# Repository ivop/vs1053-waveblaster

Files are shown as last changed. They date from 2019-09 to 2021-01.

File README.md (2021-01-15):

#VLSi SynthRoarer -- A vs1053/vs8053-waveblaster module
-------------------------------------------------
By using a vs1053/vs8053, we present to you an ideal, low-cost, easy to solder, some what compact and open source WaveBlaster module.
_________________________________________________
Introducing VLSi SynthRoarer.
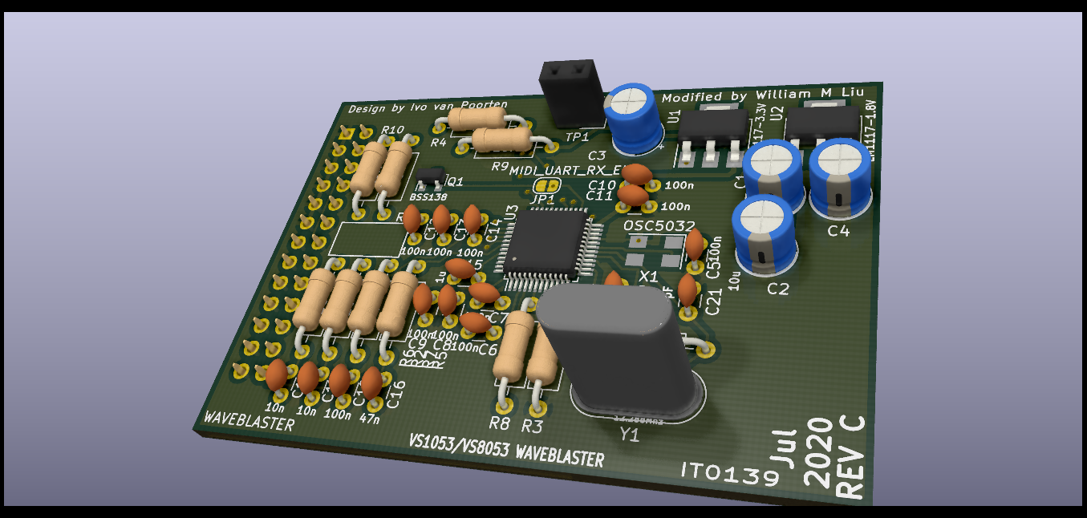
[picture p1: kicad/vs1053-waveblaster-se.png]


*Support General Midi with 128 GM1 instruments 61 GM2 Bank 0 precussion sounds up to 64 notes polyphony and stereo output @48Khz 16bit

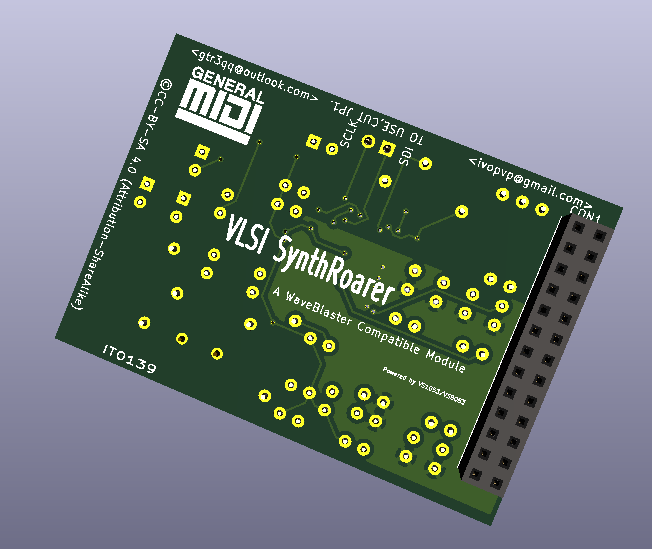
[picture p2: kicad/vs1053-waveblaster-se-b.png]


How's it sound?
--------------
Here is a sample from chip manufacture.

http://www.vlsi.fi/fileadmin/software/VS10XX/vs1053mid.mp3

Notes
------------------------
It's been tested on a old ESS 688 audiodrive sound card.

REV B and REV A is in gergber/old stable.7z

REV C IS BASICALLY REV B,their schematic is the same.

REV A = vs1053-waveblaster

REV C = vs1053-waveblaster-se

Pictures
----------------------------
Here's a view of it been fully assembled and not been. (It says REV C, but it's actually REV B).

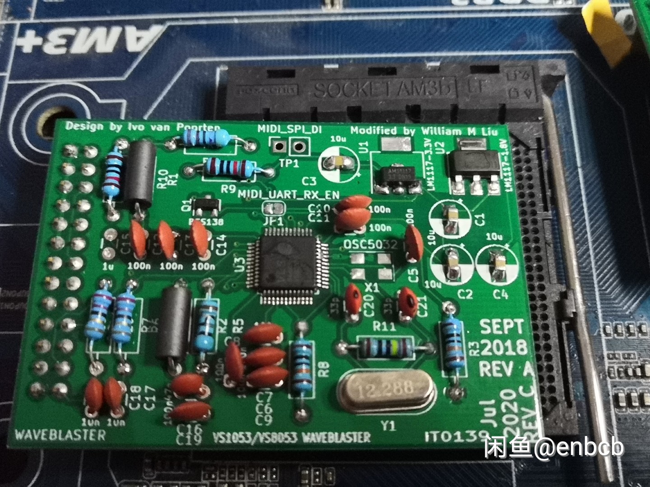
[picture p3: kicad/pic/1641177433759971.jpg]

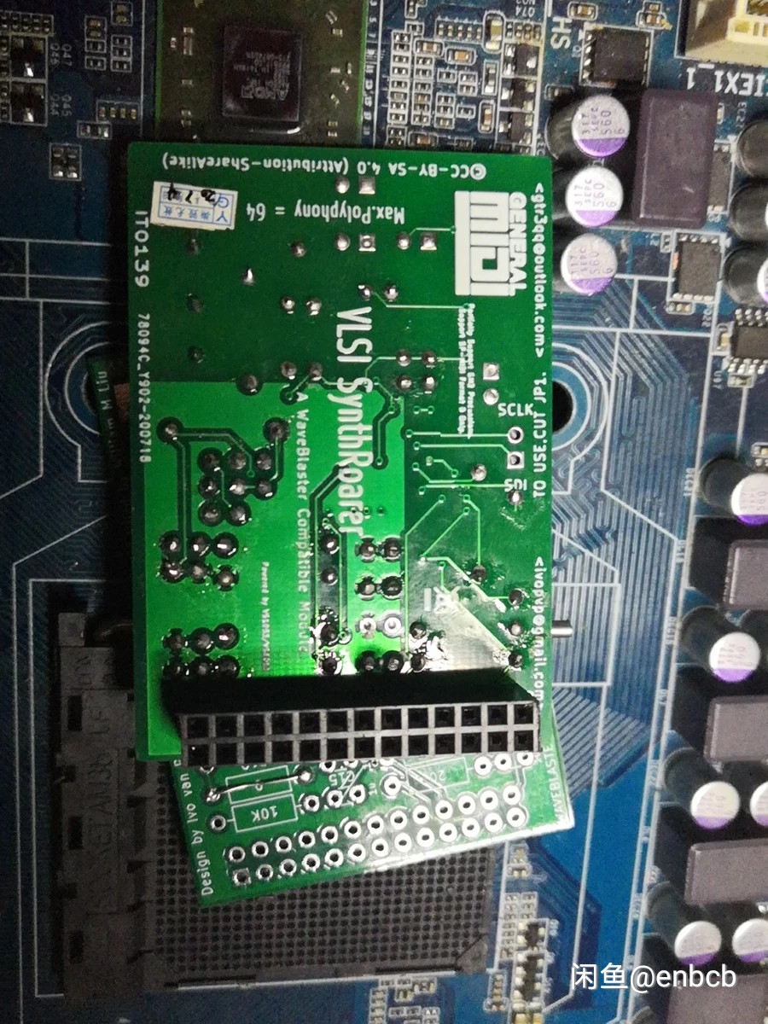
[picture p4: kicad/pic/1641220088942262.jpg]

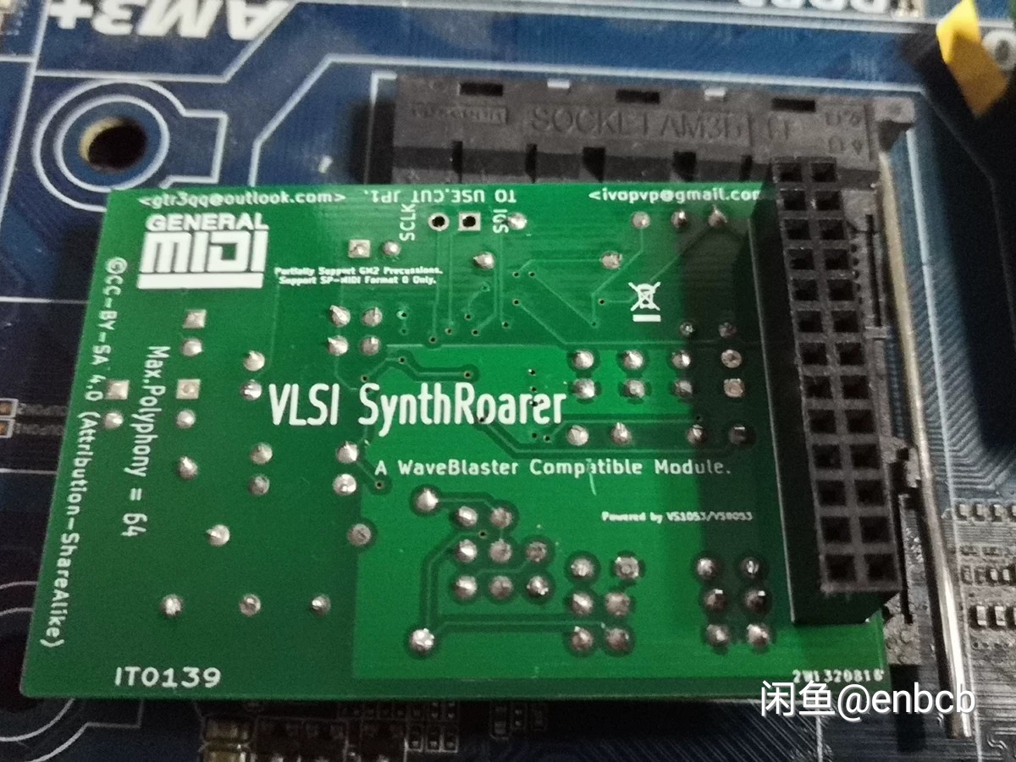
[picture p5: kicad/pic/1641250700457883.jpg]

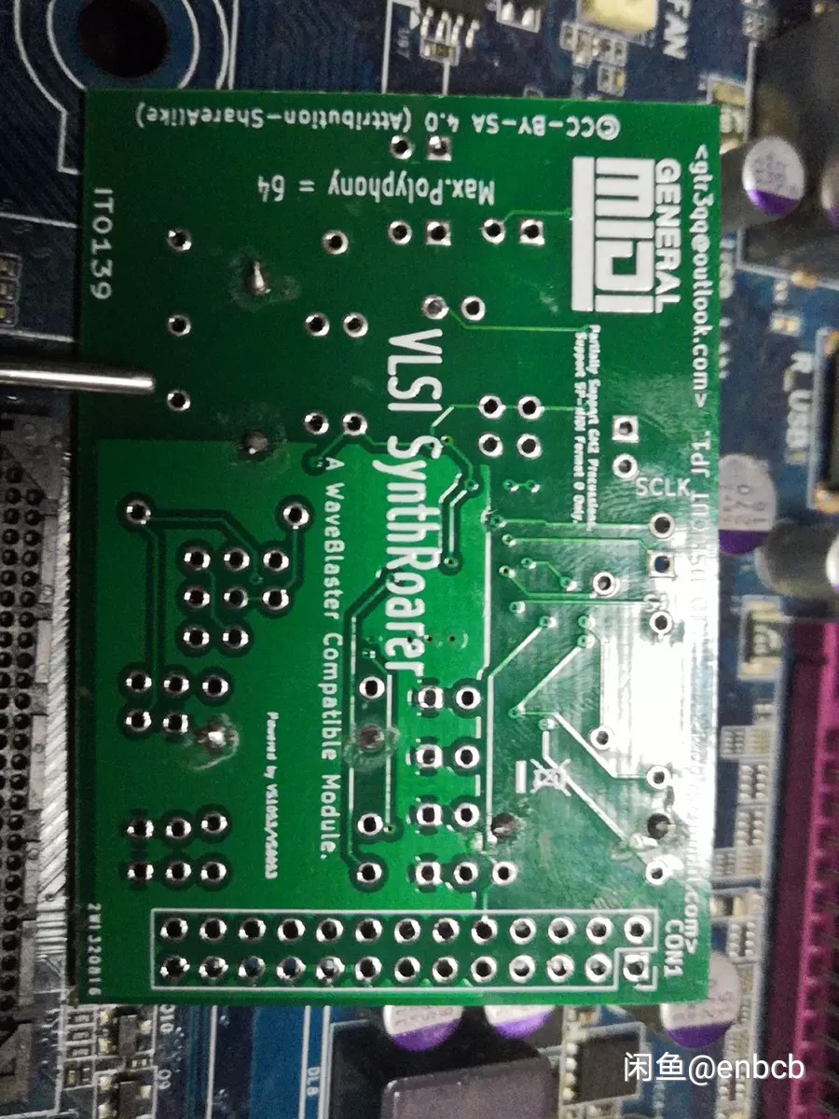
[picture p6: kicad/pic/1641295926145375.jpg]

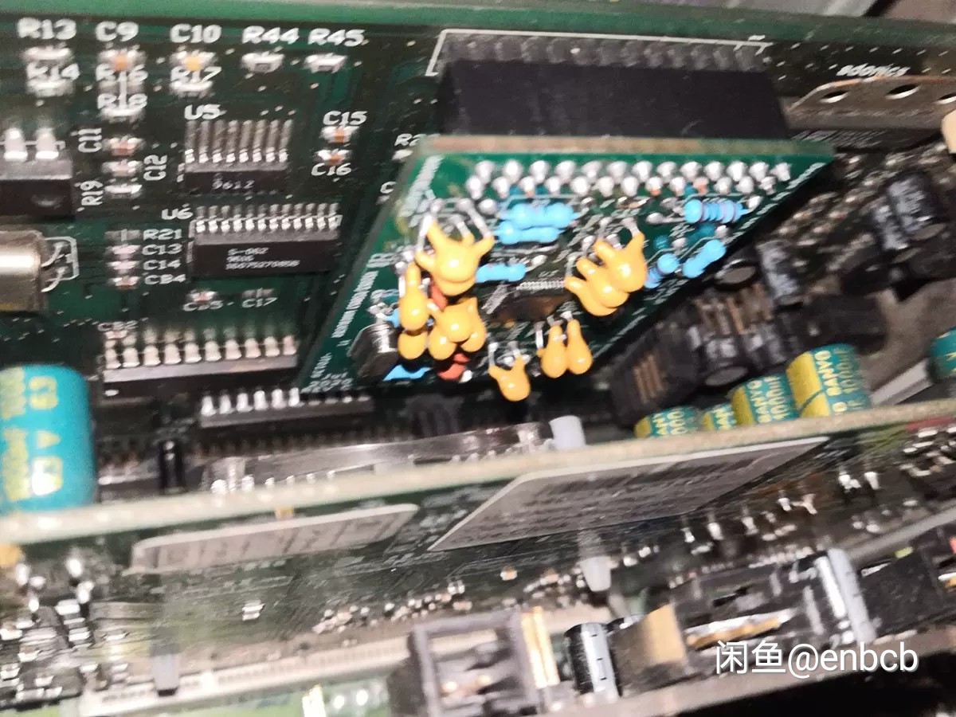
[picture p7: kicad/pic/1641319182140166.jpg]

*Look,it is working on my soundcard.

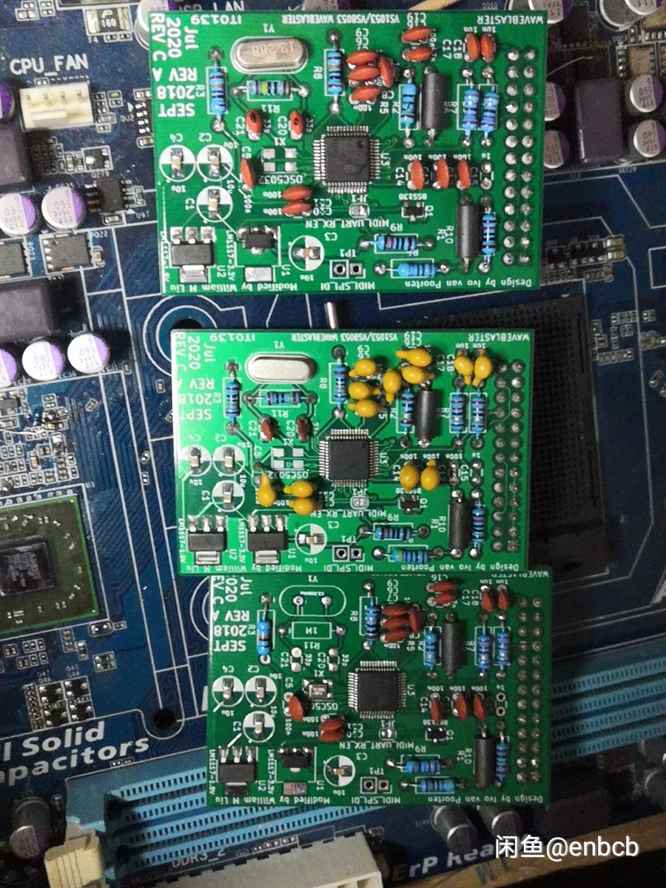
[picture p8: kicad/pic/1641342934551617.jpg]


*a. It is your choice to use crystal or oscillator.

*b. Both vs8053 and vs1053 can be used. There're no diffience in the MIDI implementation. Just buy the cheapest one.

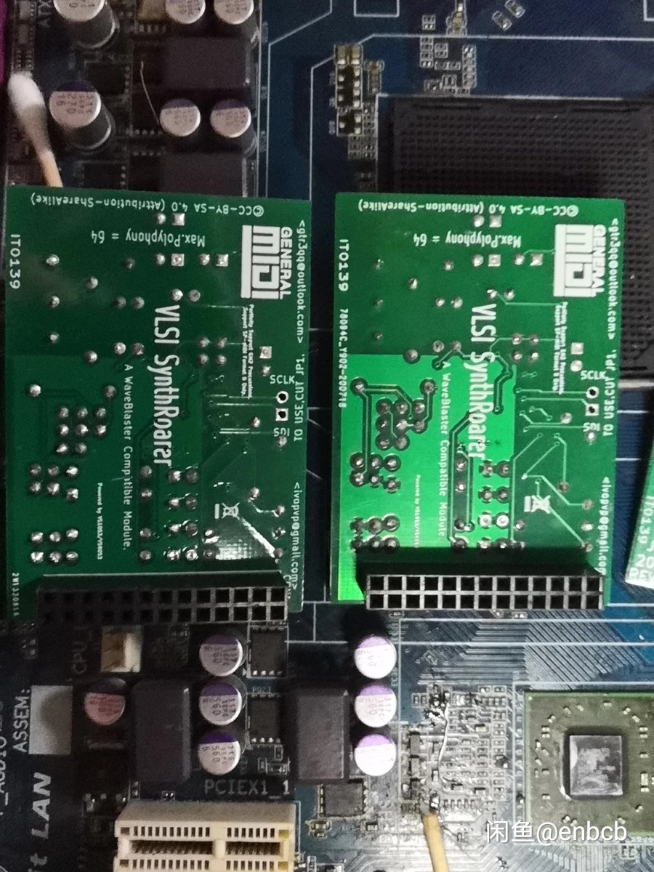
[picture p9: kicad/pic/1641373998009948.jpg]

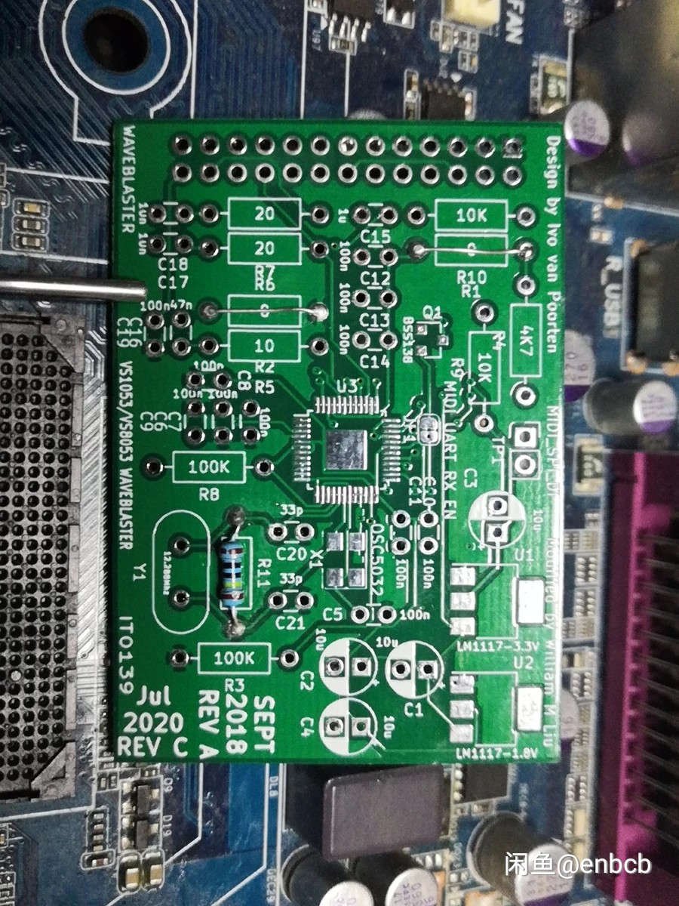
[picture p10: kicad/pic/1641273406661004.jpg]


*All values are printed on the silkscreen.

Check out another waveblaster project: https://github.com/ivop/cs9236-waveblaster

What's next?
------------------------------
1.Fully SMT-ized?(Maybe REV D?)

2.Get a proper logo?(Maybe REV D?)

3.Write a bom list?(How about right now!)

License
-----------------
<br />This work is licensed under a <a rel="license" href="http://creativecommons.org/licenses/by-sa/4.0/">Creative Commons Attribution-ShareAlike 4.0 International License</a>.

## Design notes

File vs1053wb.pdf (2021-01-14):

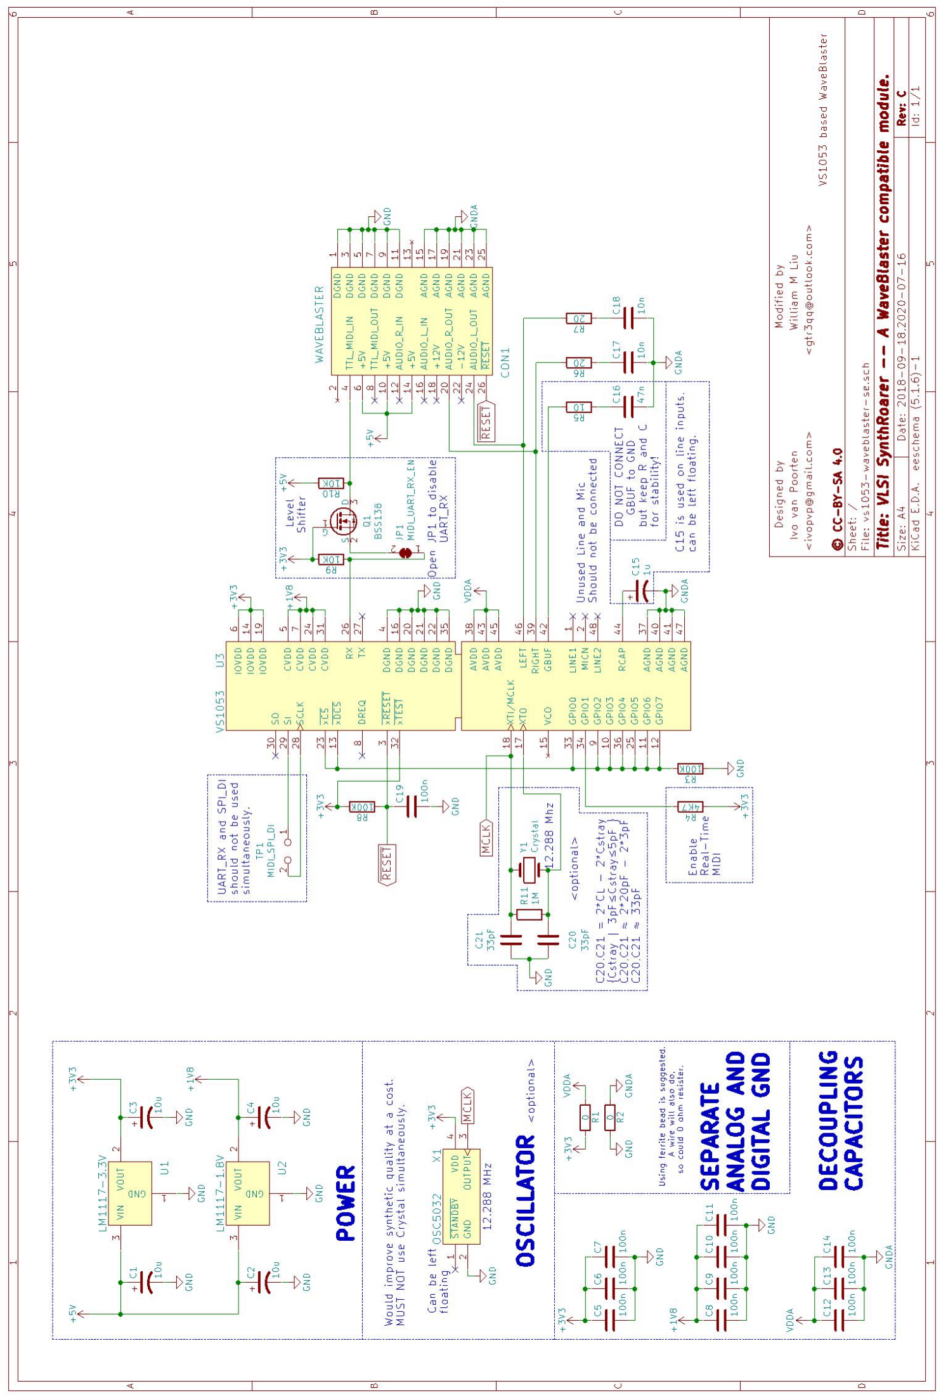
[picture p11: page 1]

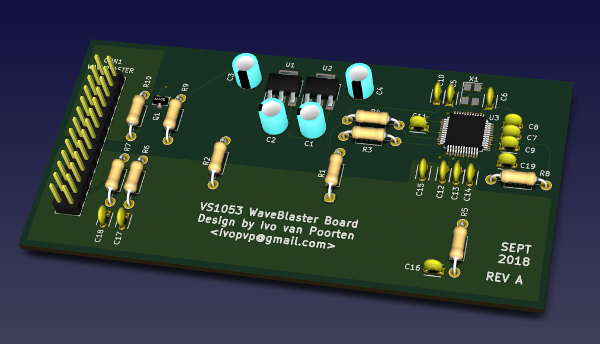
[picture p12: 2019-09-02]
kicad/vs1053wb.png

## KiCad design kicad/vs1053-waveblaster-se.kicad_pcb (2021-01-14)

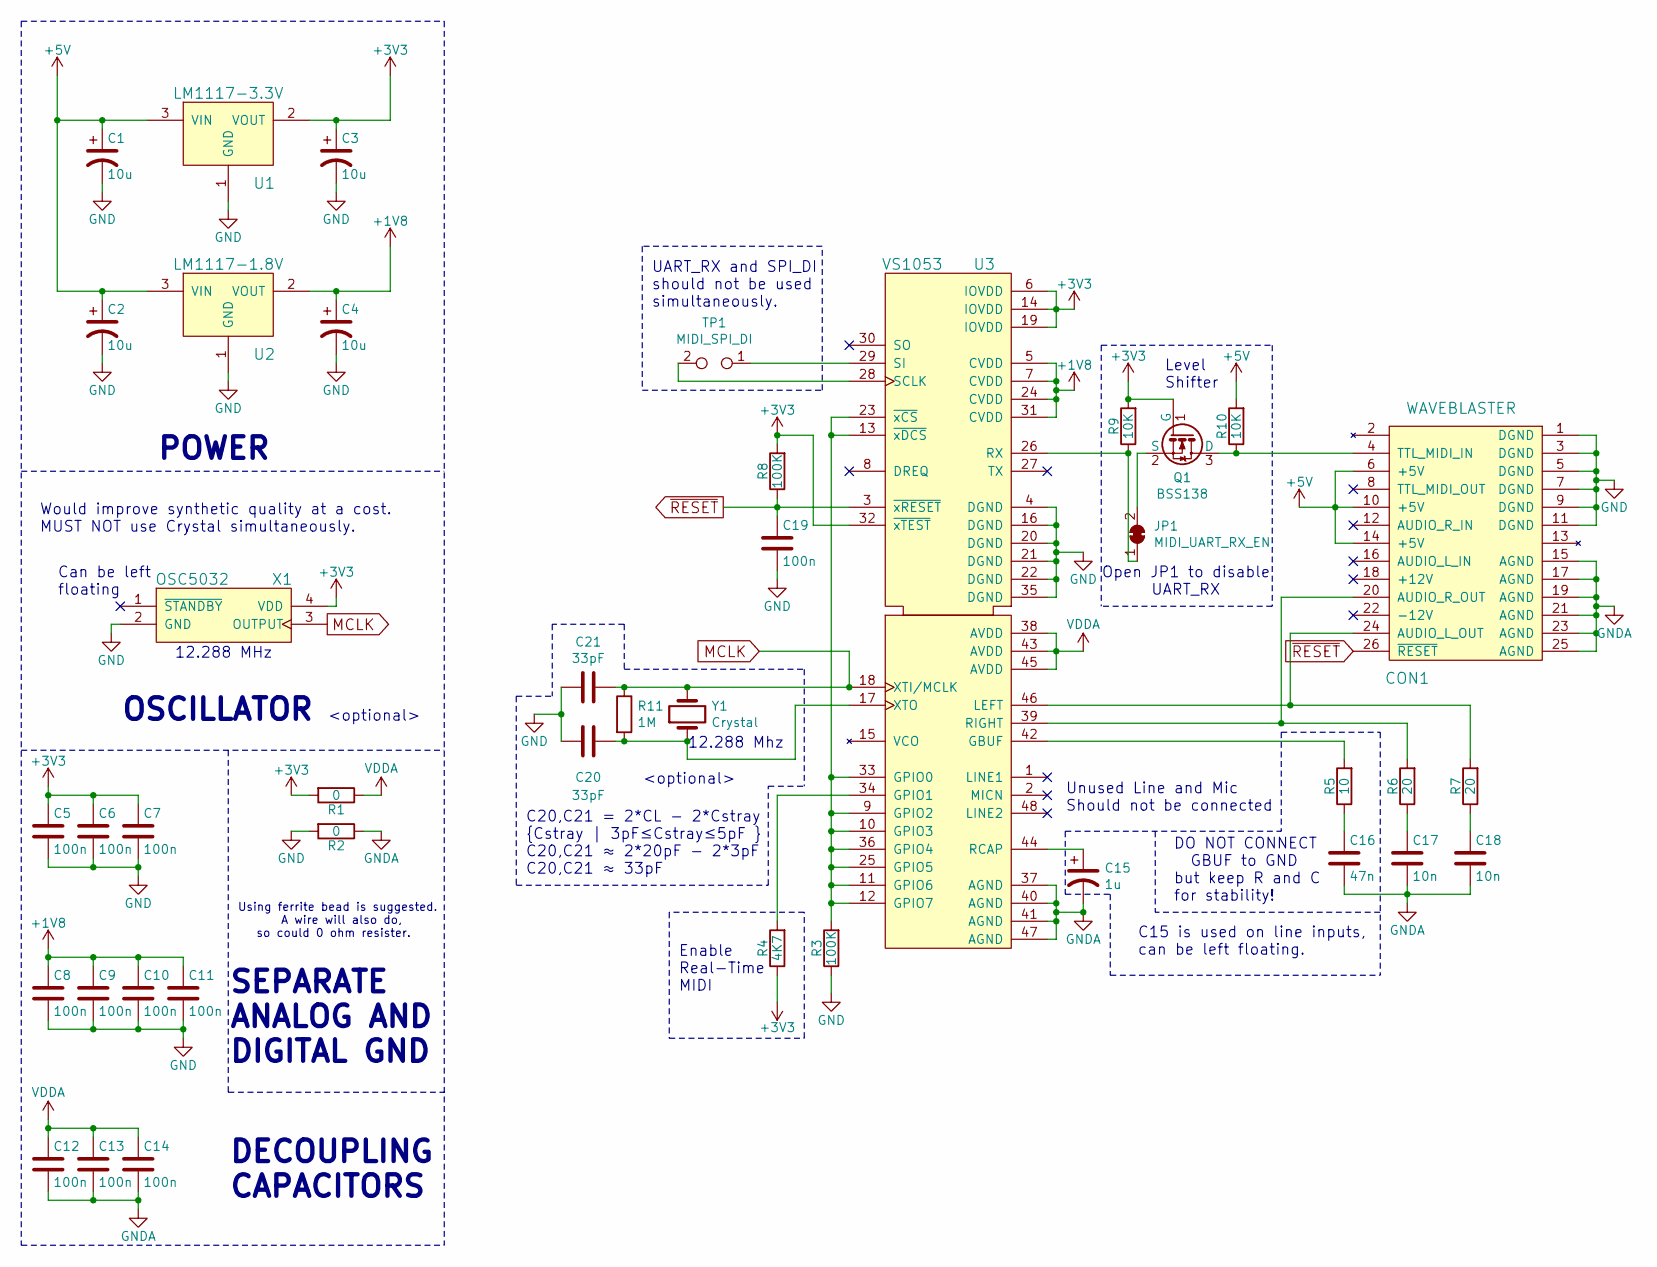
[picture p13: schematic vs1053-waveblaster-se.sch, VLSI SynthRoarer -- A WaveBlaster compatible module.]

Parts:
C1, C2, C3, C4: 10u; CP_Radial_D5.0mm_P2.50mm
C5, C6, C7, C8, C9, C10, C11, C12, C13, C14, C19: 100n; C_Disc_D3.0mm_W1.6mm_P2.50mm
C15: 1u; C_Disc_D3.0mm_W1.6mm_P2.50mm
C16: 47n; C_Disc_D3.0mm_W1.6mm_P2.50mm
C17, C18: 10n; C_Disc_D3.0mm_W1.6mm_P2.50mm
C20, C21: 33pF; C_Disc_D3.0mm_W1.6mm_P2.50mm
CON1: WAVEBLASTER; PinHeader_2x13_P2.54mm_Vertical
JP1: MIDI_UART_RX_EN; SolderJumper-2_P1.3mm_Bridged2Bar_RoundedPad1.0x1.5mm
Q1: BSS138; SOT-23
R1, R2: 0; R_Axial_DIN0207_L6.3mm_D2.5mm_P10.16mm_Horizontal
R3, R8: 100K; R_Axial_DIN0207_L6.3mm_D2.5mm_P10.16mm_Horizontal
R4: 4K7; R_Axial_DIN0207_L6.3mm_D2.5mm_P10.16mm_Horizontal
R5: 10; R_Axial_DIN0207_L6.3mm_D2.5mm_P10.16mm_Horizontal
R6, R7: 20; R_Axial_DIN0207_L6.3mm_D2.5mm_P10.16mm_Horizontal
R9, R10: 10K; R_Axial_DIN0207_L6.3mm_D2.5mm_P10.16mm_Horizontal
R11: 1M; R_Axial_DIN0207_L6.3mm_D2.5mm_P10.16mm_Horizontal
TP1: MIDI_SPI_DI; PinSocket_1x02_P2.54mm_Vertical
U1: LM1117-3.3V; SOT-223
U2: LM1117-1.8V; SOT-223
U3: VS1053; LQFP-48-1EP_7x7mm_P0.5mm_EP3.6x3.6mm
X1: OSC5032; Crystal_SMD_5032-4Pin_5.0x3.2mm
Y1: Crystal; Crystal_HC49-U_Vertical

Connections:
+1V8: C4.1, C8.1, C9.1, C10.1, C11.1, U2.2 (VOUT), U3.5 (CVDD), U3.7 (CVDD), U3.24 (CVDD), U3.31 (CVDD)
+3V3: C3.1, C5.1, C6.1, C7.1, Q1.1 (G), R1.2, R4.1, R8.2, R9.2, U1.2 (VOUT), U3.6 (IOVDD), U3.14 (IOVDD), U3.19 (IOVDD), U3.32 (~xTEST), X1.4 (VDD)
+5V: C1.1, C2.1, CON1.6 (+5V), CON1.10 (+5V), CON1.14 (+5V), R10.2, U1.3 (VIN), U2.3 (VIN)
GND: C1.2, C2.2, C3.2, C4.2, C5.2, C6.2, C7.2, C8.2, C9.2, C10.2, C11.2, C19.2, C20.1, C21.1, CON1.1 (DGND), CON1.3 (DGND), CON1.5 (DGND), CON1.7 (DGND), CON1.9 (DGND), CON1.11 (DGND), R2.2, R3.1, U1.1 (GND), U2.1 (GND), U3.4 (DGND), U3.16 (DGND), U3.20 (DGND), U3.21 (DGND), U3.22 (DGND), U3.35 (DGND), X1.2 (GND)
GNDA: C12.2, C13.2, C14.2, C15.2, C16.2, C17.2, C18.2, CON1.15 (AGND), CON1.17 (AGND), CON1.19 (AGND), CON1.21 (AGND), CON1.23 (AGND), CON1.25 (AGND), R2.1, U3.37 (AGND), U3.40 (AGND), U3.41 (AGND), U3.47 (AGND)
MCLK: C21.2, R11.1, U3.18 (XTI/MCLK), X1.3 (OUTPUT), Y1.2
unnamed: C15.1, U3.44 (RCAP)
unnamed: C16.1, R5.1
unnamed: C17.1, R6.1
unnamed: C18.1, R7.1
unnamed: C20.2, R11.2, U3.17 (XTO), Y1.1
unnamed: CON1.4 (TTL_MIDI_IN), Q1.3 (D), R10.1
unnamed: CON1.20 (AUDIO_R_OUT), R6.2, U3.39 (RIGHT)
unnamed: CON1.24 (AUDIO_L_OUT), R7.2, U3.46 (LEFT)
unnamed: JP1.1 (A), R9.1, U3.26 (RX)
unnamed: JP1.2 (B), Q1.2 (S)
unnamed: R3.2, U3.9 (GPIO2), U3.10 (GPIO3), U3.11 (GPIO6), U3.12 (GPIO7), U3.13 (~xDCS), U3.23 (~xCS), U3.25 (GPIO5), U3.33 (GPIO0), U3.36 (GPIO4)
unnamed: R4.2, U3.34 (GPIO1)
unnamed: R5.2, U3.42 (GBUF)
unnamed: TP1.1, U3.29 (SI)
unnamed: TP1.2, U3.28 (SCLK)
VDDA: C12.1, C13.1, C14.1, R1.1, U3.38 (AVDD), U3.43 (AVDD), U3.45 (AVDD)
~RESET: C19.1, CON1.26 (~RESET), R8.1, U3.3 (~xRESET)

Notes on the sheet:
Enable Real-Time MIDI
Unused Line and Mic Should not be connected
DO NOT CONNECT GBUF to GND but keep R and C for stability!
12.288 MHz
Can be left floating
POWER
DECOUPLING CAPACITORS
SEPARATE ANALOG AND DIGITAL GND
UART_RX and SPI_DI should not be used simultaneously.
12.288 Mhz
OSCILLATOR
<optional>
Would improve synthetic quality at a cost. MUST NOT use Crystal simultaneously.
Using ferrite bead is suggested. A wire will also do, so could 0 ohm resister.
C20,C21 = 2*CL - 2*Cstray {Cstray | 3pF≤Cstray≤5pF } C20,C21 ≈ 2*20pF - 2*3pF C20,C21 ≈ 33pF
Level Shifter
Open JP1 to disable UART_RX
C15 is used on line inputs, can be left floating.

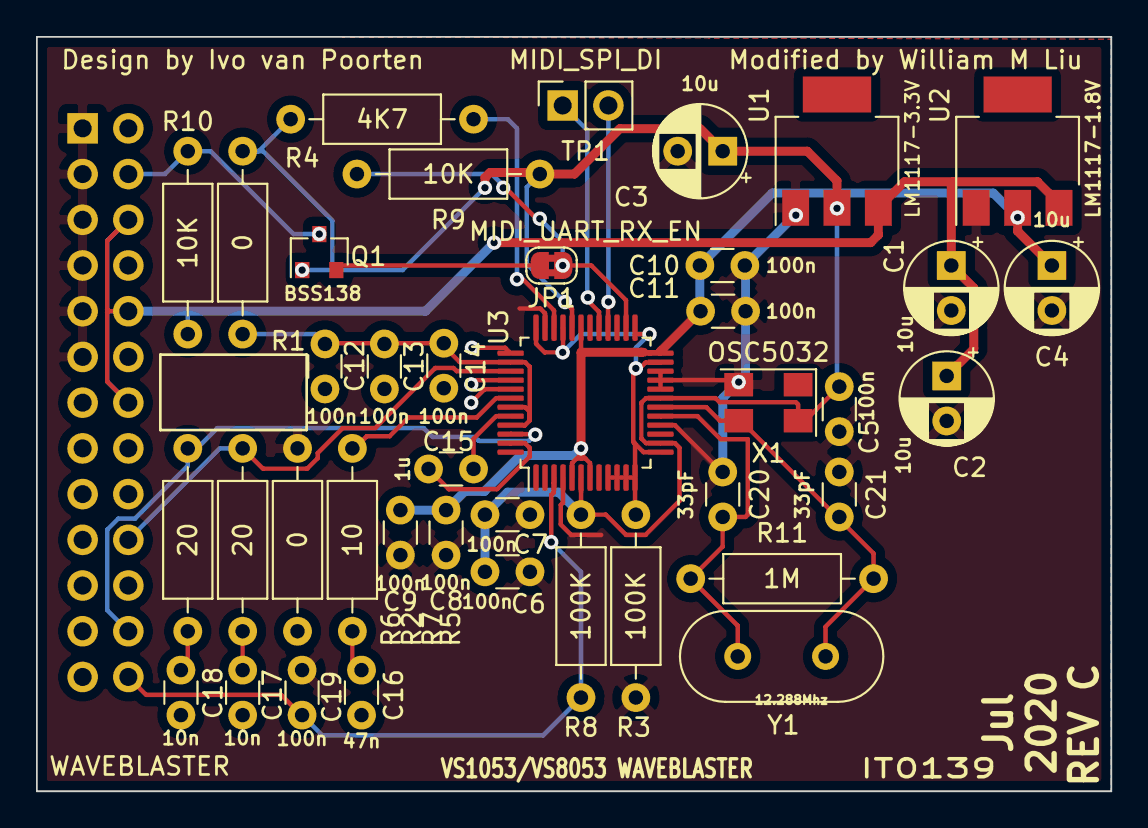
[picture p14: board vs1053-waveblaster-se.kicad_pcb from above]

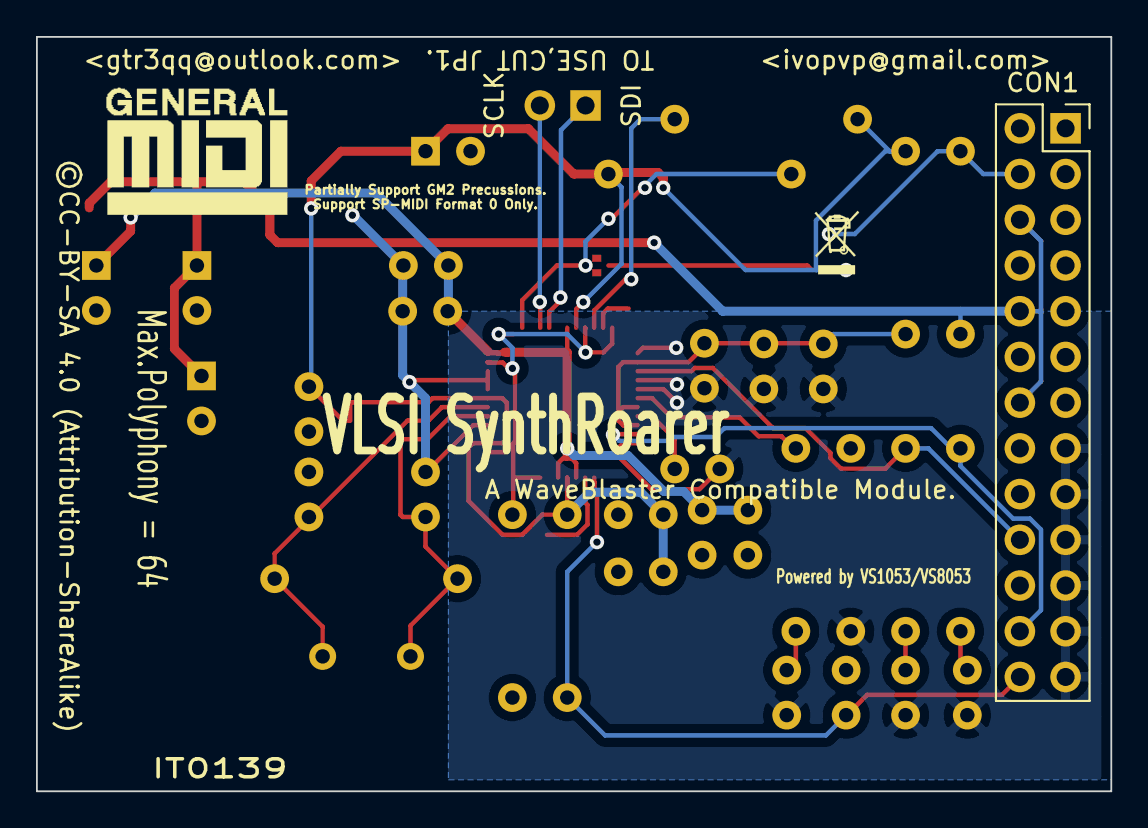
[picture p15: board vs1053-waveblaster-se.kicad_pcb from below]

Board: 2 copper layers, 59.7 x 41.9 mm, 43 parts (3 on the bottom side), 23 nets.

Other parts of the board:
G1: LOGO; logo_unrecl
G2: LOGO; logo_GM

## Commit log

2019-09-02 new VS1053 based WaveBlaster daughterboard
    [bom.csv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]
2019-09-02 link to other WB board
2020-12-31 Parched a few minor error to get it to work.
    [vs1053-waveblaster-se-B_Cu.gbr, vs1053-waveblaster-se-B_Mask.gbr, vs1053-waveblaster-se-B_SilkS.gbr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]
2021-01-14 the PCB says REV A, but it is actually REV B
2021-01-14 PCB says both A and C, but it is actually REV B i.e. reverse previous commit

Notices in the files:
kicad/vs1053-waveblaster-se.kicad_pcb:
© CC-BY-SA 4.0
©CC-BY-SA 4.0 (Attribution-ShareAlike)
